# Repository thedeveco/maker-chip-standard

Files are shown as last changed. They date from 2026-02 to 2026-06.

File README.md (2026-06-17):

# MakerChip+

> [!NOTE]
> **MakerChip+** is an open hardware standard that extends the 40 mm MakerChip / MakerCoin form factor with a polarized magnetic mount, a stacked-PCB electronics tier, onboard power, and motion. A printed token can grow into a full system component while staying interoperable across creators, docks, and forks.

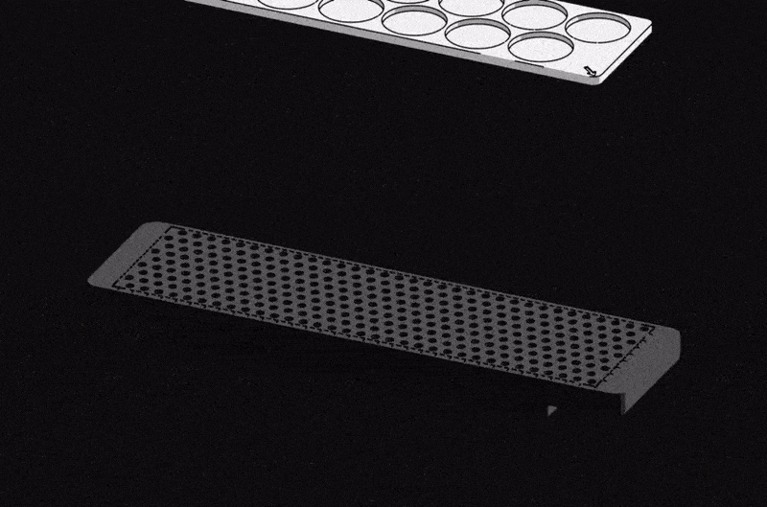
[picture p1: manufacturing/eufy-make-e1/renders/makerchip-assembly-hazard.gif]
A MakerChip+ adapter plate seating 14 chips above a 3D-printable eufyMake E1 mini bed, animated assembly loop in hazard cel-shade style


[Watch the full-quality render](https://github.com/user-attachments/assets/61c64212-e35d-4e52-ba2b-f503f769d2be) (click to play; GitHub does not autoplay video).

> [!NOTE]
> A MakerChip+ adapter plate seating 14 chips on a 3D-printable eufyMake E1 mini bed, rendered in Delta's hazard cel-shade style. The mini bed carries the same grid pattern as the ULTIM8 jig for cross-compatibility, and the adapter uses the MakerChip+ magnet pattern so every chip snaps into alignment. Both are in active development and testing. See [manufacturing/eufy-make-e1/](manufacturing/eufy-make-e1/).

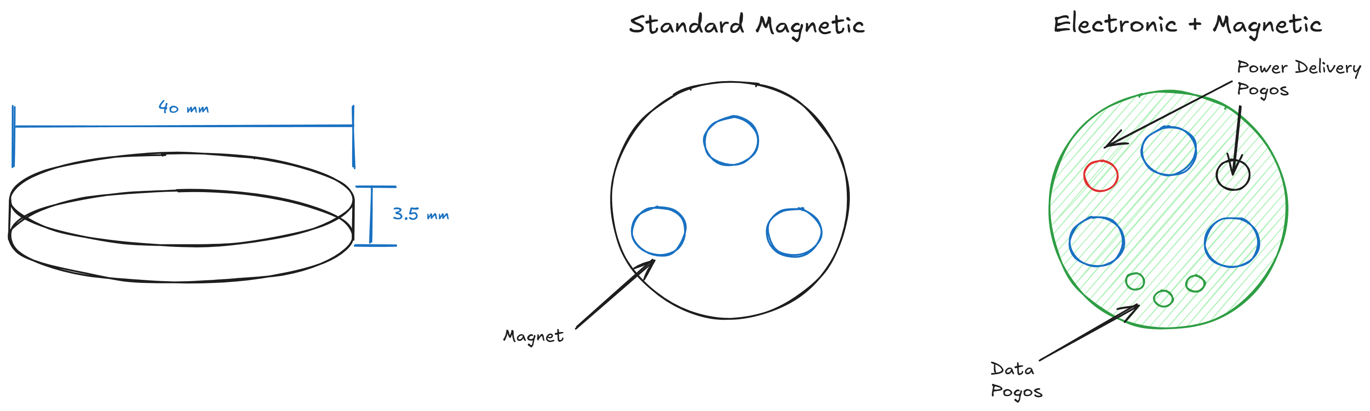
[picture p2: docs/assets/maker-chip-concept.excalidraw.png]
A small round 3D-printed chip and its layered concept diagram


## What it is

The original [MakerChip](https://makerworld.com/en/models/415825-makerchip-maker-chip-the-new-makercoin) (by [K2_Kevin](https://makerworld.com/en/@K2_Kevin), descended from the maker community's [Maker Coin](https://www.makersmuse.com/maker-s-muse-maker-coin) tradition) is a 40 mm 3D-printed token: a personalized calling card you print, trade, and collect.

MakerChip+ keeps that exact form factor and asks one question: what if the chip could do more than sit in a pocket? The standard defines the rules that let a token become magnetic, then electronic, then powered, then active, without ever breaking compatibility with the printed original or with the docks built for it.

It is a **specification**, not a single product. You build a MakerChip+ by picking a capability tier and following the spec for that tier.

## The capability tiers

| Tier | Name | What it adds |
|---|---|---|
| `1.x` | 3D Printed | The passive printed token (NFC sticker, multicolor, resin) |
| `2.x` | Magnetic Interface | Polarized magnet pair: the chip becomes mountable and orientable |
| `3.x` | PCB Stack | 3-layer PCB with the 8-pad interface, LEDs, MCU, onboard NFC |
| `4.x` | Self-Powered | Energy harvesting, battery, display, radio: no dock required |
| `5.x` | Motion | PCB coil motor, haptics, actuators: the chip moves on its own |

Higher tiers are a superset of lower ones. A `3.x` chip still mounts in a `2.x` dock; a `2.x` dock ignores the electronics it does not understand. The [compatibility rules](spec/README.md#compatibility-rules) keep the whole ecosystem interoperable.

## Quickstart (build a chip)

1. **Pick a tier** that matches what you want to ship (start at `1.x` or `2.x`).
2. **Read the spec** for that tier in [`spec/`](spec/) and preserve the [core invariants](spec/README.md#core-invariants): 40 mm diameter, 3.6 mm thickness, polarized orientation.
3. **Build it**, starting from the reference design for your tier:
   - **`1.x`** needs only a 3D printer - grab a print-ready model in [`hardware/makerchip-2.0/`](hardware/makerchip-2.0/).
   - **`2.x` magnetic** - start from the reference CAD ([`chip.step`](hardware/makerchip-2.0/chip.step), [`dock.step`](hardware/makerchip-2.0/dock.step), and `.3mf` prints), or fork the editable [public Onshape project](https://cad.onshape.com/documents/66dffec1c63767f9fad75111/w/110fc95ea174063827d47415/e/8618be80ab8abbf698550313).
   - **`3.x` PCB** - **start from the [Protoboard project](https://alpha.protoboard.xyz/board/pCOh7ogceIT44E7xwzadPOtLD8I3/_w6jix_-YGsyXYv-8ICmD)** (see the tip below). The [tscircuit source](hardware/pcb-tscircuit/) and a [KiCad scaffold](hardware/pcb-v3/) are here too.
4. **Tag your design** `MAJOR.MINOR[-variant]` (for example `MakerChip-3.1-LED-OG`) so others know what it interoperates with.

> [!TIP]
> **The fastest way to build an electronic chip is the Protoboard project.** Open the [live board](https://alpha.protoboard.xyz/board/pCOh7ogceIT44E7xwzadPOtLD8I3/_w6jix_-YGsyXYv-8ICmD) or import [`maker-chip-pcb-v4.protoboard`](docs/protoboard/maker-chip-pcb-v4.protoboard), and you get the entire system in one place: every part with its **datasheet**, a live **BOM** with vendors and cost, the **system / harness diagram**, and DRC validation. Fork it, swap a part, and everything updates with you. Details in [docs/protoboard/](docs/protoboard/).

## Documentation

| Document | Contents |
|---|---|
| [spec/README.md](spec/README.md) | Core invariants, versioning system, compatibility matrix |
| [spec/magnetic.md](spec/magnetic.md) | The polarized magnetic standard (>= 2.0) |
| [spec/tiers.md](spec/tiers.md) | Full major-version tiers (1.x - 5.x) and variants |
| [spec/interface.md](spec/interface.md) | The 8-pad standard electrical interface (>= 3.0) |
| [spec/docks.md](spec/docks.md) | Docks: the inverse mating part |
| [spec/roadmap.md](spec/roadmap.md) | Open questions and what must be locked before v2.0 freeze |
| [docs/protoboard/](docs/protoboard/) | **Protoboard project - the recommended 3.x starting point**: importable file plus BOM, datasheets, and system diagram |
| [hardware/makerchip-2.0/](hardware/makerchip-2.0/) | Chip + dock CAD (STEP) and print-ready 3MF models for the 2.x magnetic tier |
| [hardware/pcb-tscircuit/](hardware/pcb-tscircuit/) | The 3.x PCB defined as code (tscircuit source + rendered layer previews) |
| [hardware/pcb-v3/](hardware/pcb-v3/) | KiCad reference design (3.1-class) |
| [hardware/accessories/](hardware/accessories/) | Printable extras (chip roll / holder) |
| [manufacturing/eufy-make-e1/](manufacturing/eufy-make-e1/) | 3D-printable mini bed plate + 14-chip adapter for batch UV printing |

## Contributing

Fork it, pick a tier, preserve the invariants, tag your version, and open a PR if you have improved a reference design. Designs that deviate from the form factor or compatibility rules are welcome as forks or `-variant` releases, but do not promote to mainline. A full contributing guide is on the way.

## Credit and prior art

MakerChip+ is an independent standard built on the **concept and dimensions** of the original MakerChip / Maker Coin, not on anyone's model files. The original MakerChip by K2_Kevin is released under CC BY-NC-SA; this standard reuses only the interoperability idea and the 40 mm form factor (specifications are not copyrightable) and ships its own clean-room designs.

- Original MakerChip: https://makerworld.com/en/models/415825-makerchip-maker-chip-the-new-makercoin
- MakerChip community catalog: https://makerchip.app
- Maker Coin origin (Maker's Muse / Angus Deveson): https://www.makersmuse.com/maker-s-muse-maker-coin

## License

This project is licensed under **Creative Commons Attribution-ShareAlike 4.0 International (CC BY-SA 4.0)**. You may share, remix, and build commercially, provided you give attribution and license derivatives under the same terms. See [LICENSE](LICENSE) once added (license file pending in the next setup phase).

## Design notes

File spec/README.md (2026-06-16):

# MakerChip+ Standard

The reference standard for **MakerChip+**: a 40 mm x 3.6 mm poker-chip-sized open-hardware artifact. This document defines the **form-factor invariants**, the **versioning system** (major capability tiers, minor augmentations), and the **compatibility rules** that keep the ecosystem interoperable across creators, sponsors, and forks.

This directory is the standard. The repository root [README](../README.md) is the front door.

- [Magnetic standard (>= 2.0)](magnetic.md)
- [Major version tiers (1.x - 5.x) and variants](tiers.md)
- [8-pad standard interface (>= 3.0)](interface.md)
- [Docks](docks.md)
- [Roadmap and open questions](roadmap.md)

---

## 0. Origin

MakerChip+ standardizes a magnetic and electronic mounting system for the MakerChip, originally devised by [K2_Kevin](https://makerworld.com/en/models/415825-makerchip-maker-chip-the-new-makercoin), itself an evolution of the community [Maker Coin](https://www.makersmuse.com/maker-s-muse-maker-coin) created by Angus Deveson (Maker's Muse).

This standard is independent of any original model files. It reuses only the interoperability concept and the 40 mm form factor (specifications are not copyrightable) and defines its own clean-room designs and license. See the root README for full credit and prior art.

### Concept

Layered concept diagram of the chip showing bottom, middle, and top stack

### Prototype

- [Onshape CAD file](https://cad.onshape.com/documents/66dffec1c63767f9fad75111/w/110fc95ea174063827d47415/e/8618be80ab8abbf698550313)

---

## 1. Core invariants

These never change. Anything that breaks them is a **branch**, not a version.

| Property | Spec | Rationale |
| --- | --- | --- |
| Diameter | **40 mm** | Standard poker-chip footprint; tactile recognition |
| Thickness | **3.6 mm** (0.8 + 2.0 + 0.8) | Fits standard poker-chip racks/storage; allows 3-layer PCB stack |
| Stack convention | bottom / middle / top | Layered architecture even for 3D-printed chips |
| Orientation | **Polarized** (see [magnetic.md](magnetic.md)) | Forward-compatibility with all electrical/mechanical interfaces  |
| License | **CC BY-SA 4.0** | Share, remix, and sell with attribution and same-license terms |

> [!WARNING]
> **Form factor is the contract.** All major versions MUST preserve diameter, thickness, and orientation polarity. A "MakerChip+" that is 50 mm or 5 mm thick is a different product. Call those branches/variants explicitly (for example `MakerCoin`, `MakerSlab`).

---

## 2. Versioning system

### 2.1 Semantics

`MAJOR.MINOR[-VARIANT]`

- **MAJOR** - capability tier. Each tier unlocks a new class of functionality (passive form -> magnetic interface -> electronics -> power -> motion). Higher tier = strict superset of lower-tier capabilities (or compatible substitution).
- **MINOR** - additive augmentation within a tier. Does not break compat with same-major peers. Can be combined freely.
- **VARIANT** - named branch for non-conforming or experimental designs (for example `2.x-maglev`, `3.x-mini`). Variants do not promote to mainline.

### 2.2 Examples

| Version | Meaning |
|---|---|
| `1.0` | Plain 3D-printed disc |
| `1.1` | 3D print + embedded NFC sticker |
| `1.2+1.3` | 3D print + NFC + multicolor surface |
| `2.0` | Magnetic interface added |
| `3.1` | PCB stack with LEDs |
| `4.2-eink` | Self-powered chip with e-ink, branch variant |
| `5.0-experimental` | Motion-capable prototype |

### 2.3 Compatibility rules

> [!NOTE]
> **Forward/backward compat.** A chip at version `N.x` MUST physically interoperate with any accessory/dock built for version `M.x` where `M <= N`, provided the accessory only relies on capabilities present in version `M`. Higher-tier features are simply not used.

This works because:
- Form factor is identical
- Magnet positions/polarity (>= 2.0) never move
- Pad positions (>= 2.2) never move
- 8-pad signal map (>= 3.0) is fixed (see [interface.md](interface.md))

---

## 8. Compatibility matrix

| Capability | 1.x | 2.x | 3.x | 4.x | 5.x |
|---|---|---|---|---|---|
| 40mm x 3.6mm form factor | Yes | Yes | Yes | Yes | Yes |
| NFC tag (sticker or chip) | 1.1+ | Yes | 3.3+ | Yes | Yes |
| Magnet alignment | No | Yes | Yes | Yes | Yes |
| Bottom contact pads | No | 2.2+ | Yes | Yes | Yes |
| 8-pad standard signals | No | No | Yes | Yes | Yes |
| Onboard MCU | No | No | 3.2+ | Yes | Yes |
| Self-powered operation | No | No | No | Yes | Yes |
| Active motion | No | No | No | No | Yes |

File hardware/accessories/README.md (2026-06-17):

# Accessories

Printable extras for the MakerChip+ ecosystem.

| File | What it is |
|---|---|
| `maker-chip-roll.3mf` | A roll / holder for storing and carrying a stack of chips |

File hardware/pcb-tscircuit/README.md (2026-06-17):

# PCB (tscircuit source)

The MakerChip+ 3-layer PCB defined as code with [tscircuit](https://tscircuit.com). This is the editable source behind the `3.x` PCB tier - the same board that is mirrored and validated on [Protoboard](../../docs/protoboard/).

## Layers

| File | Layer |
|---|---|
| [`top.circuit.tsx`](top.circuit.tsx) | Top PCB - silkscreen art and LEDs |
| [`middle.circuit.tsx`](middle.circuit.tsx) | Middle PCB - cutouts for components and the magnet pair |
| [`bottom.circuit.tsx`](bottom.circuit.tsx) | Bottom PCB - the 8-pad pogo interface |
| [`shared.tsx`](shared.tsx) | Shared dimensions and helpers |

Rendered previews of every layer (PCB + schematic) are in [`__snapshots__/`](__snapshots__/). Branding/glyph helpers (`omega-glyph.ts`, `lucide-magnet.ts`, `oshw-logo.ts`, `branding-paths.ts`) and build/export scripts live in [`scripts/`](scripts/).

## Build

Requires [bun](https://bun.sh) and the tscircuit CLI (`tsci`).

```
bun install
tsci dev      # live preview in the browser
```

> [!NOTE]
> `node_modules/`, `dist/`, and tscircuit caches are gitignored. Third-party datasheets referenced during design (for example a micro-battery PDF) are not redistributed here.

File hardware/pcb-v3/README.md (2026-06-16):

# PCB v3 - MakerChip+ Reference Design (3.1-class)

KiCad project for the `3.x` PCB-stack tier of the [MakerChip+ standard](../../spec/README.md). This is the electronic MakerChip+: a 40 mm 3-layer PCB stack powered through the 8-pad pogo-pin interface.

> [!NOTE]
> These KiCad files are an early scaffold. The validated design currently lives as the live Protoboard project "Maker Chip PCB - V3"; see the [snapshot](../../docs/protoboard/README.md) for the parts list, BOM, and electrical specs.

## Specifications

- 40 mm diameter, 3.0 to 3.6 mm thick (0.8 + 2.0 + 0.8 mm stack)
- Powered via a base-station / dock motherboard through the [8-pad interface](../../spec/interface.md)
- `3.1`-class: 4 white LEDs for an internal glow effect, ATtiny85 MCU, two 15 x 2 mm magnets, NFC tag

## Files

| File | Purpose |
|---|---|
| `emakerchip.kicad_pro` | KiCad project |
| `emakerchip.kicad_sch` | Schematic |
| `emakerchip.kicad_pcb` | PCB layout |

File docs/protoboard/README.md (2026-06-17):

# Protoboard Project

[Protoboard](https://protoboard.xyz) is where the MakerChip+ PCB is designed and validated, and it is the **single best starting point for a `3.x` build**. Instead of chasing parts and specs across a dozen tabs, the board hands you the entire system in one place.

## Open or import it

- **Live board:** https://alpha.protoboard.xyz/board/pCOh7ogceIT44E7xwzadPOtLD8I3/_w6jix_-YGsyXYv-8ICmD
- **Importable file:** [`maker-chip-pcb-v4.protoboard`](maker-chip-pcb-v4.protoboard) - download it and open at [alpha.protoboard.xyz](https://alpha.protoboard.xyz) to load the whole project locally.

## What you get for free

- Every component with its **datasheet** attached
- A live **BOM** with vendors, pack sizes, and per-board cost
- The **system / harness diagram** - how the 8-pad interface wires to the ATtiny85 and the LEDs
- **DRC** validation and design notes

This is why we point builders at Protoboard first: fork the board, swap a part, and the BOM, datasheets, and connection checks update with you.

## V3 snapshot (2026-04-30)

The markdown below is an exported snapshot of the earlier **Maker Chip PCB - V3** board (`Qy7JVPyQZbhWuvUfJOMx8`). The live board above is the current MakerChip+ design; these files are kept as a readable, offline record.

- [board-summary.md](board-summary.md) - parts, harnesses, electrical specs, layout
- [plan.md](plan.md) - requirements, tasks, tags, open considerations
- [bom.md](bom.md) - bill of materials with vendors, pack sizes, per-board cost
- [session-log.md](session-log.md) - log of changes made via the Protoboard MCP

## Version history

Earlier Protoboard JSON exports are in [`versions/`](versions/): `v1`, `v2`, `v3`.

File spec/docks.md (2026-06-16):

# Docks

Back to [standard overview](README.md).

A **Dock** is the inverse of a chip: the interface a MakerChip+ plugs into. Docks are how chips do anything beyond sitting in a pocket. The standard defines the chip; docks are built to spec so any compliant chip can interface with any compliant dock at the same tier or below.

> [!NOTE]
> **Dock = inverse of chip.** If the chip exposes magnets at fixed polarity and pads at fixed positions, the dock provides the matching mating magnets (opposite polarity for snap-in alignment) and pogo pins (or copper pads) at the same coordinates. The polarized magnet pair guarantees the chip can only seat one way, so pads always line up correctly.

A reference `2.0` dock (the inverse of the magnetic chip) is provided as CAD in [`hardware/makerchip-2.0/dock.step`](../hardware/makerchip-2.0/dock.step).

## What docks deliver

Depending on chip tier:

- **Mechanical hold** (>= 2.0) - magnetic snap-in. The chip stays put on a hat, badge, lanyard, wall, etc.
- **Power** (>= 2.2 / >= 3.0) - VCC/GND through pads. Docks supply 5V to drive LEDs, MCUs, displays.
- **Data** (>= 3.0) - DATA/CLK/CS lines for read/write. Reprogram a chip, transfer game data, register an ID.
- **Identification** (>= 3.0 or >= 1.1) - read NFC/RFID or pad-based ID to authenticate the chip and trigger a system response (door unlock, profile load, score increment).

## Example docks

| Dock type | Description | Chip tier needed |
|---|---|---|
| **Hat clip / lanyard / pin** | Single magnet pocket; chip snaps in, no electronics | >= 2.0 |
| **Multi-slot badge** | Wearable badge with several flush cutouts; swap chips in/out for display, ID, art | >= 2.0 (display variants >= 3.x) |
| **Charging dock** | Pogo-pin base supplies 5V; LEDs/MCU on chip light up | >= 3.0 |
| **Reader / scanner** | Reads NFC tag or pad-based ID; reports to host system | >= 1.1 (NFC) or >= 3.0 (pads) |
| **Door unlock dock** | Magnetic seat + pogo pins, reads chip ID, triggers actuator/access system | >= 3.0 |
| **Game console / cartridge slot** | Pogo pins + storage protocol; chip acts as removable cartridge or save token | >= 3.5 |
| **Display kiosk** | Multi-chip array; each chip drives a tile of a larger display | >= 3.4 (RGB) |

## Why docks matter at higher tiers

Low-tier (1.x) chips work passively; a sticker is enough. Higher tiers depend on the dock to be useful. A `3.2` chip with an MCU is a paperweight without a dock supplying power. A `3.5` storage cartridge is just plastic without a system that knows how to read it.

Designing a tier without designing the matching dock is half the work. **Mainline tier specs SHOULD ship with at least one reference dock design.**

> [!NOTE]
> **VIP access dock (Fallout-style "Platinum Chip").** At an event, attendees receive a `1.1` or `3.x` Platinum Chip: a limited-run, serialized MakerChip+. To enter the VIP area, the attendee places the chip onto a wall-mounted **access dock**. The polarized magnets snap the chip into the only correct orientation, the dock reads the chip's NFC or pad-based ID, validates it against an authorized list, and unlocks the door. The same hardware pattern works for badge unlocks, hidden booths, scavenger hunts, or backstage access.

## Dock conformance

Docks SHOULD declare the **maximum tier** they support (`Dock 3.0` handles >= 3.0 chips and ignores higher-tier features on `4.x`/`5.x` chips placed in it). A `Dock 5.x` is the inverse: it must handle every tier below it gracefully.

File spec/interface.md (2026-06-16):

# The 8-Pad Standard Interface (>= 3.0)

Back to [standard overview](README.md).

> [!WARNING]
> **Still in development.** The 8-pad map below is the **current working draft** for the `3.x` electrical contract. Pad count, positions, and signal assignments may change or expand (more pads, alternate maps for specialized variants) before being frozen. Treat as provisional until marked stable in this repo.

Defined on the bottom face. 3 mm exposed copper, fixed positions.

| Pad | Signal | Notes |
|---|---|---|
| 1 | VCC (5V) | Power in |
| 2 | GND | Ground |
| 3 | DATA | MOSI / SDA / generic |
| 4 | CLK | SCK / SCL |
| 5 | CS / RST | Chip select / reset |
| 6 | MISO / GPIO | Bidir |
| 7 | GPIO / PWM | Bidir |
| 8 | ANALOG | ADC-capable |

> [!NOTE]
> **Why this map.** It covers SPI, I2C, UART (with pin reuse), and analog/PWM in 8 pads. Every common MCU footprint maps cleanly. Pads 1-2 are always power; 3-8 are programmable.

## Reference pinout (ATtiny85)

The `3.1` reference design maps the 8 pads to an ATtiny85 as follows:

| Pad | Signal | ATtiny85 Pin |
|-----|---|---|
| 1 | VCC (5V) | Pin 8 |
| 2 | GND | Pin 4 |
| 3 | DATA (MOSI/SDA)  | Pin 5 (PB0) |
| 4 | CLK (SCK/SCL) | Pin 7 (PB2) |
| 5 | CS/RST | Pin 1 (RESET) |
| 6 | MISO/GPIO | Pin 6 (PB1) |
| 7 | GPIO/PWM | Pin 3 (PB4) |
| 8 | ANALOG | Pin 2 (PB3/ADC3)|

Pad positions and the full board breakdown live in the reference snapshot: see [`docs/protoboard/bom.md`](../docs/protoboard/bom.md) and [`docs/protoboard/board-summary.md`](../docs/protoboard/board-summary.md).

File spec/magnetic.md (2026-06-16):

# The Magnetic Standard (>= 2.0)

Back to [standard overview](README.md).

The defining innovation. Two **15 x 2 mm N52 disc magnets** embedded in the middle layer at fixed positions, with **opposite polarities** facing the same direction.

> [!TIP]
> **Why polarized.** Two flipped magnets means the chip can only seat in **one rotational orientation** when placed against any mating surface with a matching magnet pattern. This eliminates the "user flips chip upside-down" failure mode for electrical pads, NFC antennas, and so on. Future tiers (PCB pads, displays, antennas) inherit this orientation lock for free.

## Magnet placement spec

*(Exact center-to-center distance, tolerance, and reference axis to be locked in the v2.0 spec - currently 16 mm CtC. Placement diagram pending; see [roadmap.md](roadmap.md).)*

The reference chip and mating dock CAD live in [`hardware/makerchip-2.0/`](../hardware/makerchip-2.0/) (`chip.step`, `dock.step`), modeled in the [public Onshape project](https://cad.onshape.com/documents/66dffec1c63767f9fad75111/w/110fc95ea174063827d47415/e/8618be80ab8abbf698550313).

## Optional shielding (2.x minor)

A thin steel shim or mu-metal layer on the **non-interface side** can null the magnetic field on that face, useful when the back of the chip is meant to sit against a credit card, hard drive, or another magnet-sensitive surface.

## MagLev variant (`2.x-maglev`)

A floating-magnet implementation using a commercial maglev base plus an embedded ferromagnetic disc. This is a branch variant; it does not deprecate the `2.x` mainline. See the [Hackaday MagLev tag](https://hackaday.com/tag/maglev/) for prior art.

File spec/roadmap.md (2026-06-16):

# Roadmap and Open Questions

Back to [standard overview](README.md).

> [!IMPORTANT]
> **Things to lock down before the v2.0 freeze:**
> - [ ] Exact magnet center-to-center distance + tolerance (currently 16 mm CtC, plus/minus ?)
> - [ ] Magnet orientation reference axis (which way is "+X"? silkscreen marker?)
> - [ ] Pad positions for the 2.2 passive-pad variant: same map as 3.0 8-pad, or a simpler 2-pad?
> - [ ] **8-pad map freeze** (currently in development, may expand)
> - [ ] Reference dock design(s) per tier, bundled with the mainline tier spec
> - [ ] Conformance test / certification process, or is this purely honor-system?
> - [ ] NFC antenna footprint reservation in the 3.0 PCB stack (so 3.0 -> 3.3 does not require a board redesign)
> - [ ] Magnet placement diagram image (see [magnetic.md](magnetic.md))

## Resolved

- **License decision** - settled on CC BY-SA 4.0. See the root [README](../README.md#license). LICENSE file to be added in the repo setup phase.

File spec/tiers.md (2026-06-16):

# Major Version Tiers and Variants

Back to [standard overview](README.md).

## 4. Major version tiers

### `1.x` - 3D Printed (passive form)

The entry tier. Anyone with a 3D printer can produce a compliant chip.

| Minor | Augmentation | Notes |
|---|---|---|
| 1.0 | Plain mono filament print | Baseline; no inserts |
| 1.1 | Pause-print **NFC tag insert** | NTAG213/215 sticker dropped mid-print. See [Bambu NFC tag](https://us.store.bambulab.com/products/nfc-tag-with-adhesive?skr=yes&id=42872074240136&modelId=415825) |
| 1.2 | Multicolor / AMS print | Logos, identity art baked in |
| 1.3 | Laser-etched or engraved surface | Post-process detail |
| 1.4 | Multi-material (TPU rim, etc.) | Grip, durability |
| 1.5 | Resin / SLA finish | High-detail collectible runs |

> [!NOTE]
> **Reference build.** A `1.1+1.2` chip = multicolor 3D-printed disc with a hidden NFC tag. Looks like swag, scans like a key.

### `2.x` - Magnetic Interface

Adds the polarized magnet pair. **First tier where the chip becomes a system component**, not just a token. Full spec in [magnetic.md](magnetic.md).

| Minor | Augmentation |
|---|---|
| 2.0 | Dual 15 x 2 mm magnets, opposite polarity (mainline spec) |
| 2.1 | + Steel shim shielding (one-sided field) |
| 2.2 | + Bottom-side **passive contact pads** (no electronics, just brass/copper inserts for snap-in chargers, ID readers, etc.) |

> [!NOTE]
> **Why 2.x is a tier and not a 1.x minor.** Adding magnets fundamentally changes what the chip *is*. It becomes mountable, orientable, and modular. Every higher tier inherits this.

> [!NOTE]
> **Reference CAD.** The `2.0` chip and its mating dock are in [`hardware/makerchip-2.0/`](../hardware/makerchip-2.0/).

### `3.x` - PCB Stack (electronics, externally powered)

Three-layer PCB sandwich. The middle layer has cutouts for components and magnets. The bottom layer exposes the **8-pad standard interface** (see [interface.md](interface.md)) for power and data via pogo-pin docks. The top layer is the canvas (silkscreen, art, surface-mount LEDs).

| Minor | Augmentation |
|---|---|
| 3.0 | Bare 3-layer PCB stack with 8-pad interface |
| 3.1 | + Indicator LEDs (current `Maker Chip PCB - V3` reference design) |
| 3.2 | + MCU (ATtiny85 or equivalent) |
| 3.3 | + **On-PCB NFC antenna** + tag IC (NT3H2111, ST25DV): replaces sticker, MCU can read/write |
| 3.4 | + Addressable RGB LEDs (WS2812 / SK6812) |
| 3.5 | + Onboard storage / data-cartridge variant ("DOOM-on-a-chip" use case) |

> [!NOTE]
> **Reference design.** The current open-source PCB lives in this repo as a `3.1`-class design. See [`hardware/pcb-v3/`](../hardware/pcb-v3/) for the KiCad project and [`docs/protoboard/`](../docs/protoboard/) for a snapshot of the live Protoboard project.

**Prior art / references:**
- [Hackster: Light-up poker chip](https://www.hackster.io/AlexWulff/light-up-poker-chip-7fa67f) - LED chip ref (3.1)
- [Reddit: PCB poker set](https://www.reddit.com/r/electronics/comments/opowu0/pcb_poker_set/) - full set fabrication
- [PokerChipForum: RFID table experiment](https://www.pokerchipforum.com/threads/experimenting-with-a-diy-rfid-table-and-broadcast-overlay.88715/post-2141059) - application
- [Reddit: NFC antenna design advice](https://www.reddit.com/r/PrintedCircuitBoard/comments/1f5q0j3/need_advice_on_nfc_antenna_design_and_component/) - 3.3 antenna sizing
- [GitHub: PCB Business Card](https://github.com/Raziz1/PCB_Business_Card) - antenna trace example
- [Instructables: PCB Business Card with NFC](https://www.instructables.com/PCB-Business-Card-With-NFC-Make-Yours-With-NFC-QR-/) - build guide
- [PCBSync: NFC antenna PCB](https://pcbsync.com/nfc-antenna-pcb/) - antenna design reference

### `4.x` - Self-Powered

Onboard energy. The chip stops needing a dock to do anything.

| Minor | Augmentation |
|---|---|
| 4.0 | Wireless power harvesting (Qi pad, NFC field, RF) |
| 4.1 | + Internal battery (LiPo / LiSOCl2 coin) |
| 4.2 | + Power-management IC + deep-sleep modes |
| 4.3 | + E-ink / Memory LCD display |
| 4.4 | + Always-on indicator (low-current LED) |
| 4.5 | + BLE / sub-GHz radio (full wireless duplex) |

**References:**
- [Instructables: Wireless energy transmission via PCB](https://www.instructables.com/Wireless-Energy-Transmission-System-Only-Using-PCB/)
- [ABLIC wireless power ICs](https://www.ablic.com/en/semicon/products/rtc/wireless-power-ic/intro/)
- [MDPI: Electronics 13(2), 426](https://www.mdpi.com/2079-9292/13/2/426) - academic ref
- [Analog Devices AN-138FC](https://www.analog.com/en/resources/app-notes/an-138fc.html)
- [TI E2E: wireless power transfer](https://e2e.ti.com/support/power-management-group/power-management/f/power-management-forum/380718/wireless-power-transfer)

### `5.x` - Motion

Active mechanical capability. The chip moves, vibrates, or actuates something on its own.

| Minor | Augmentation |
|---|---|
| 5.0 | PCB coil motor (planar / axial-flux) |
| 5.1 | Haptic / vibration motor (LRA or coin) |
| 5.2 | Microactuator / piezo |
| 5.3 | Combined motion + display + power (full active chip) |

**References:**
- [Hackaday: PCB motor tag](https://hackaday.com/tag/pcb-motor/)
- [PCBWay: PCB motor design guidelines](https://www.pcbway.com/blog/Engineering_Technical/PCB_Motor_Design_Guidelines.html)

---

## 5. Branches and variants

Use a `-suffix` instead of bumping major when the design **deviates from the form factor or compat rules** but is still MakerChip+-adjacent.

| Variant | Description |
|---|---|
| `2.x-maglev` | Floating-magnet implementation using a commercial maglev base |
| `3.x-mini` | Reduced-diameter PCB chip (for example 25 mm): non-conforming, explicit |
| `3.x-thick` | >3.6 mm stack for high-component-count PCB |
| `*-collectible` | Limited-run sponsor/creator edition (for example a Fallout collab) |
| `*-cartridge` | Non-standard pad map for a proprietary dock (for example a game system) |

> [!WARNING]
> **Variants do not promote.** A variant never becomes the next mainline major. If a deviation proves valuable enough to absorb, mainline gets the upgrade with a new major number, NOT by adopting the variant's suffix.

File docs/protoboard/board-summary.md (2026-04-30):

# Maker Chip PCB - V3 — Board Summary

- **Board ID:** `Qy7JVPyQZbhWuvUfJOMx8`
- **URL:** https://alpha.protoboard.xyz/board/pCOh7ogceIT44E7xwzadPOtLD8I3/Qy7JVPyQZbhWuvUfJOMx8
- **Parts:** 20 (17 functional + 2 magnets + 1 NFC tag, 14 unique templates)
- **Harnesses:** 20
- **DRC:** PASS

## Description

A poker-chip-sized PCB device with 3 stacked layers (2× 0.8 mm + 1× 2 mm middle). Features 4 white LEDs for internal glow effect, powered via pogo-pin interface. Middle layer contains 15 mm magnets and component cutouts.

## Stack Structure

- **Top PCB (0.8 mm):** Silkscreen design on top, LEDs/resistors on bottom
- **Middle PCB (2 mm):** Cutouts for LEDs, resistors, ATtiny85, and magnets; two 15×2 mm magnets with opposite polarities
- **Bottom PCB (0.8 mm):** 8× 3 mm copper pads for pogo pins on bottom; traces and optional components on top

## 8-Pad Standard Interface

| Pad | Signal | ATtiny85 Pin |
|-----|---|---|
| 1 | VCC (5V) | Pin 8 |
| 2 | GND | Pin 4 |
| 3 | DATA (MOSI/SDA)  | Pin 5 (PB0) |
| 4 | CLK (SCK/SCL) | Pin 7 (PB2) |
| 5 | CS/RST | Pin 1 (RESET) |
| 6 | MISO/GPIO | Pin 6 (PB1) |
| 7 | GPIO/PWM | Pin 3 (PB4) |
| 8 | ANALOG | Pin 2 (PB3/ADC3)|

## Electrical

- Supply: 5 V DC via pogo pins
- LEDs: 4× white in parallel, each with 120 Ω series resistor
- Total LED current: ~60 mA (4 × 15 mA)
- ATtiny85 drives PWM pulse effects on PB4

## Parts (with positions)

| Name | Template ID | Position (x, y) |
|---|---|---|
| White LED 1 | basic-mpjDjlaA2KYMB05qyPX1R | (-40, 640) |
| White LED 2 | basic-mpjDjlaA2KYMB05qyPX1R | (210, 640) |
| White LED 3 | basic-mpjDjlaA2KYMB05qyPX1R | (680, 620) |
| White LED 4 | basic-mpjDjlaA2KYMB05qyPX1R | (930, 620) |
| 120Ω Resistor 1 | basic-fFVpV0slY_0ycHSXpgPcp | (-40, 840) |
| 120Ω Resistor 2 | basic-fFVpV0slY_0ycHSXpgPcp | (210, 840) |
| 120Ω Resistor 3 | basic-fFVpV0slY_0ycHSXpgPcp | (680, 820) |
| 120Ω Resistor 4 | basic-fFVpV0slY_0ycHSXpgPcp | (930, 820) |
| Pad 1 - VCC (5V) | basic-NLkZFikHo6YDudwjzZbog | (400, 0) |
| Pad 2 - GND | basic-848t6FXjZg-gFcYJHxtV4 | (400, 1060) |
| Pad 3 - DATA | basic-VYPSKHr3RS2GLnCUEqvgd | (-40, 60) |
| Pad 4 - CLK | basic-IFiLhx3i8ZHFZPVNEg8n0 | (-40, 210) |
| Pad 5 - CS/RST | basic-rVRacUFPbQDq3LhNcpwAH | (-40, 360) |
| Pad 6 - MISO/GPIO | basic-_xR1FA-npyLAzmcU1FuL4 | (820, 60) |
| Pad 7 - GPIO/PWM | basic-uaMJdW7PbbgWcAmpVx_dB | (820, 220) |
| Pad 8 - ANALOG | basic-bNdPFE75fJqbc11ZdhxV5 | (820, 380) |
| ATtiny85 MCU | basic-1AGk7mINFuKOXGWMz54X8 | (400, 300) |
| Magnet 1 (N-up, 15×2 mm) | basic-YyWx7p_6bcMBmPNF_7r77 | (1180, 300) |
| Magnet 2 (S-up, 15×2 mm) | basic-YyWx7p_6bcMBmPNF_7r77 (2nd inst.) | (1180, 500) |
| NFC Tag (NTAG215, 25×25 mm) | basic-Rlhr-s9wEdMSbvUFO1J4g | (1180, 700) |

## Topology

- ATtiny85 (center) connects to all 8 pads + 4 LED chains
- Each LED → 120 Ω resistor → GND pad
- VCC pad → ATtiny85
- 20 harnesses total, all DRC-clean

## Layout Notes (info-level)

6 suboptimal handle orientations (cosmetic only, no DRC errors):
- R1, R3, R4 handles face bottom but neighbor is to side
- GND pad handle faces top but neighbor (R3) is right
- ATtiny85 ↔ White LED 1 handle pair faces wrong direction

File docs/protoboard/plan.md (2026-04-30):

# Maker Chip PCB - V3 — Plan

**Status as of 2026-04-30:** 8/8 requirements validated.

## Requirements

| # | Status | Content |
|---|---|---|
| 1 | validated  | Supply 5V DC power through pogo pin interface to illuminate 4 white LEDs |
| 2 | validated  | Each LED must have a current-limiting resistor to prevent burnout |
| 3 | validated  | LEDs must fit within cutouts in middle PCB layer (0603 package: 1.6×0.8×0.55 mm) |
| 4 | validated  | Total PCB stack thickness: 3.6 mm (0.8 + 2.0 + 0.8 mm) |
| 5 | validated  | Bottom surface must be flat with only exposed copper pads for pogo pins |
| 6 | validated  | Top surface must be flat for silkscreen design application |
| 7 | validated  | 8-Pad Standard Interface: VCC, GND, DATA, CLK, CS/RST, MISO/GPIO, GPIO/PWM, ANALOG — all 3 mm exposed copper pads |
| 8 | validated  | ATtiny85 MCU connected to pads 3–8 for ISP programming and LED pulse control |

## Tasks

### Done
- Finalize LED and resistor component selection from LCSC (NCD0603W3, RC0603FR-07120RL)
- Design LED circuit schematic (4 parallel LED strings, each with series resistor)
- Define pogo pin pad layout on bottom PCB

### To Do
- Create middle layer cutout pattern (4 LEDs, 4 resistors, 2 magnets — verify fit)
- Route traces on bottom PCB (pogo pads → component positions via vias to top PCB)
- Design top PCB silkscreen artwork (logo + LED glow cutout)
- Generate Gerber files for fabrication (all 3 PCB layers)
- Order components from LCSC (4+ LEDs, 4+ resistors)

## Tags

LED, PCB, pogo-pin, wearable

## Open Considerations

- NFC (NTAG215 sticker) added but not yet captured in requirements/cutouts. Decide whether NFC tag mounts on top, embeds in middle, or is post-assembly applied.
- Magnet placement requirement currently mentions "two 15×2 mm magnets with opposite polarities" — confirm orientation in middle layer cutouts.

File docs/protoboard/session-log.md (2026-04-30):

# Protoboard Session Log — 2026-04-30

Maker Chip PCB - V3 (`Qy7JVPyQZbhWuvUfJOMx8`) on https://alpha.protoboard.xyz

## Audit (initial state)

- 17 parts, 20 harnesses
- DRC: PASS
- 6 info-level layout warnings (suboptimal handle directions; cosmetic)
- 8 requirements, 6 validated / 2 pending
- BOM: $0.00 — no supplier prices set

## Actions Taken

### Plan: closed pending requirements

Marked validated based on board state already satisfying both:

1. **8-Pad Standard Interface** (`f6f0c128-…`) — all 8 pads present and named correctly.
2. **ATtiny85 MCU connected to pads 3–8** (`a3b752f8-…`) — 11 harnesses confirm full pad-to-MCU coverage.

### BOM: added LCSC supplier records

| Template ID | Vendor | LCSC PN | Unit USD |
|---|---|---|---|
| basic-mpjDjlaA2KYMB05qyPX1R (LED) | LCSC | C158100 | $0.012 |
| basic-fFVpV0slY_0ycHSXpgPcp (120Ω R) | LCSC | C114640 | $0.005 |
| basic-1AGk7mINFuKOXGWMz54X8 (ATtiny85) | LCSC | C89852  | $1.20 |

### Added new parts

- **Magnet (15×2 mm N52)** — single template `basic-YyWx7p_6bcMBmPNF_7r77` placed twice (Magnet 1 N-up at 1180,300; Magnet 2 S-up at 1180,500). Sourced from AplysiaTech 40-pack on Amazon (B0FNX1XP21, $25.99/pack → $0.65 ea).
- **NFC Tag (NTAG215, 25×25 mm)** — template `basic-Rlhr-s9wEdMSbvUFO1J4g` at (1180, 700). InnoHHustle 50-pack on Amazon (B0F24L4GDM, $8.99/pack → $0.18 ea).

### Final cost estimate

- Project total: **$36.26** (one pack each)
- Per-board real consumption: **~$2.78**

## Tool Errors Encountered

- `upsert_bom_supplier_record` rejected initial `{name, partNumber, priceUSD, ...}` field shape. Correct schema uses `supplierVendorName`, `supplierPartNumber`, `supplierManufacturerPartNumber`, `supplierCurrentPriceUSD`, `supplierPackQuantity`, `supplierPurchaseUrl`.
- First Amazon RFID URL returned generic homepage via `summary` mode. `text` mode on the resolved Amazon `dp` URL succeeded and returned full product specs.

## Open Items / Suggestions

- Rotate handles on R1, R3, R4, ATtiny85, LED 1, GND pad to fix the 6 info warnings (cosmetic).
- Add NFC tag to requirements (currently absent from spec) and decide its layer placement.
- Magnet/NFC parts are blank placeholders with no interfaces — consider adding interface definitions if future DRC checks should validate placement.

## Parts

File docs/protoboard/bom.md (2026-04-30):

# Maker Chip PCB - V3 — Bill of Materials

**Project total (one of each pack):** $36.26 USD
**Per-board component cost (real consumption):** ~$2.78 USD
**Pack overage:** 1 magnet pack (40) + 1 NFC pack (50) cover ~20+ boards.

## Components

| Component | Vendor | Part Number | Pack Qty | Pack Price | Unit Price | Qty/Board | Per-Board Cost |
|---|---|---|---|---|---|---|---|
| White LED (NCD0603W3) | LCSC | C158100 | 1 | $0.012 | $0.012 | 4 | $0.048 |
| 120 Ω Chip Resistor 0603 | LCSC | C114640 (RC0603FR-07120RL) | 1 | $0.005 | $0.005 | 4 | $0.020 |
| ATtiny85-20SU MCU | LCSC | C89852 | 1 | $1.20 | $1.20 | 1 | $1.20 |
| N52 Disc Magnet 15×2 mm | Amazon | B0FNX1XP21 (AplysiaTech) | 40 | $25.99 | $0.65 | 2 | $1.30 |
| NFC Sticker NTAG215 25×25 mm | Amazon | B0F24L4GDM (InnoHHustle) | 50 | $8.99 | $0.18 | 1 | $0.18 |

## Pad Components (PCB Features, No Supplier)

These are exposed copper pads on the bottom PCB — fabricated as part of the board, not purchased separately:

- Pad 1 — VCC (5 V), 3 mm
- Pad 2 — GND, 3 mm
- Pad 3 — DATA, 3 mm
- Pad 4 — CLK, 3 mm
- Pad 5 — CS/RST, 3 mm
- Pad 6 — MISO/GPIO, 3 mm
- Pad 7 — GPIO/PWM, 3 mm
- Pad 8 — ANALOG, 3 mm

## Purchase Links

- LEDs: https://www.lcsc.com/product-detail/C158100.html
- Resistors: https://www.lcsc.com/product-detail/C114640.html
- ATtiny85: https://www.lcsc.com/product-detail/C89852.html
- Magnets: https://amzn.to/4tD4pup
- NFC Tags: https://amzn.to/4n0ZIbn

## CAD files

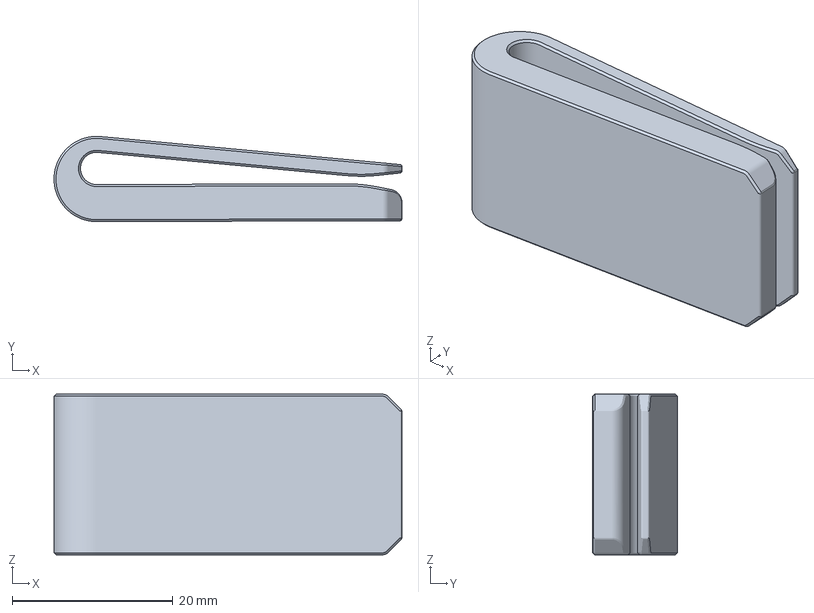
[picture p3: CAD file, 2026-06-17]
hardware/makerchip-2.0/hat-clip-dock.3mf
43.3 x 10.6 x 20.0 mm

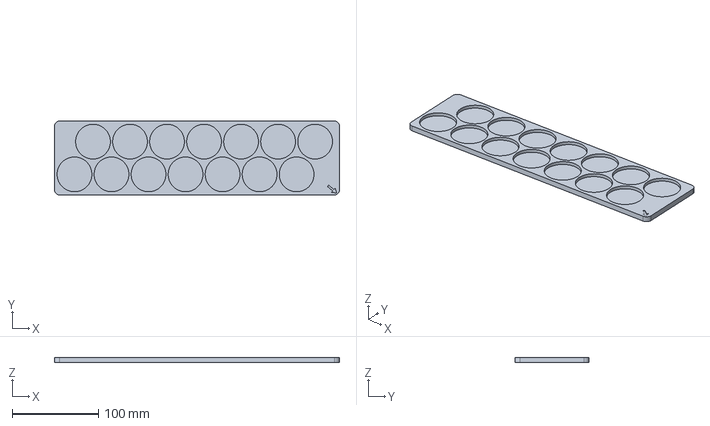
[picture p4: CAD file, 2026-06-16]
manufacturing/eufy-make-e1/adapter-plate.step
331.0 x 86.0 x 6.10 mm

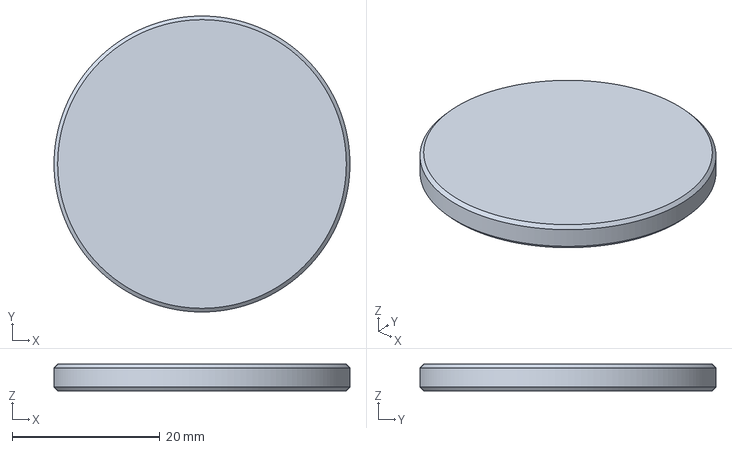
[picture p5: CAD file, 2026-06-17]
hardware/makerchip-2.0/chip-clear.3mf
40.0 x 40.0 x 3.60 mm

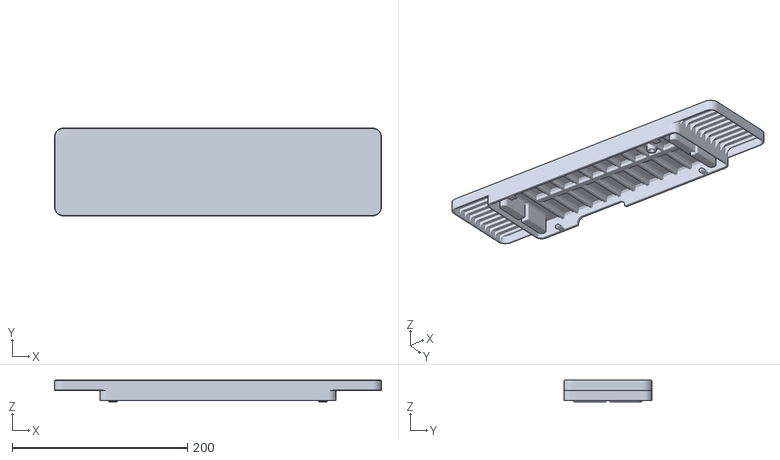
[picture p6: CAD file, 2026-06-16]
manufacturing/eufy-make-e1/og-eufy-mini-bed-low-profile-reinforced.stl
373.5 x 100.3 x 24.8

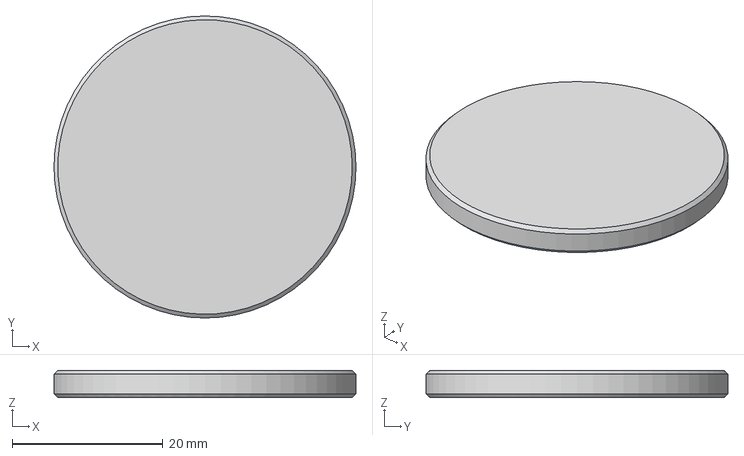
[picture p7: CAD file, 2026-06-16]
hardware/makerchip-2.0/chip.step
40.0 x 40.0 x 3.60 mm

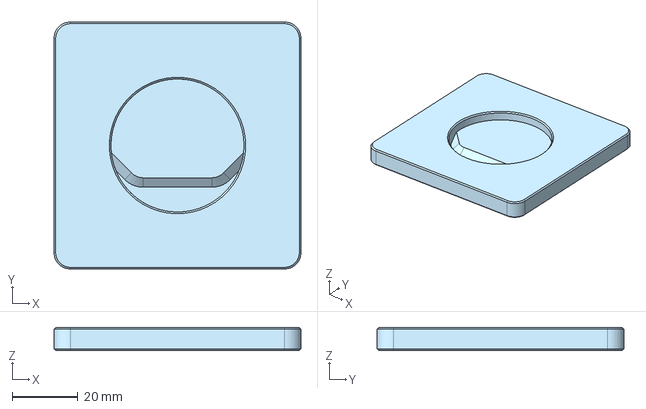
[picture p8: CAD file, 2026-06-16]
hardware/makerchip-2.0/dock.step
75.0 x 75.0 x 7.00 mm

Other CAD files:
hardware/makerchip-2.0/chip.3mf
manufacturing/eufy-make-e1/mini-bed-plate.blend

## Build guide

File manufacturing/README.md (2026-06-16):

# Manufacturing

Production tooling, jigs, and fixtures for making MakerChip+ chips at small scale.

These are not part of the standard itself; they are the practical aids that make a batch of chips repeatable to produce, decorate, and assemble.

| Platform | Contents |
|---|---|
| [eufy-make-e1/](eufy-make-e1/) | A 3D-printable mini bed plate and a 14-chip adapter for the eufyMake E1 UV printer |

> [!WARNING]
> Everything here is in active development and testing. Dimensions, magnet positions, and grid alignment are not yet frozen.

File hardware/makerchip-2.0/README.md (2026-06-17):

# MakerChip+ 2.0 - Chip and Dock CAD

Mechanical CAD for the `2.x` magnetic tier of the [MakerChip+ standard](../../spec/README.md): the chip and its mating dock.

This is the [magnetic standard](../../spec/magnetic.md) realized as solid geometry. The polarized magnet pair lets the chip seat in exactly one orientation against the dock.

## Files

| File | What it is |
|---|---|
| `chip.step` | The MakerChip+ 2.0 chip (40 mm, dual 15 x 2 mm magnet pockets) |
| `dock.step` | The mating dock (inverse magnet pattern for snap-in alignment) |
| `chip.3mf` | Print-ready MakerChip+ 2.0 chip |
| `chip-clear.3mf` | Print-ready chip, clear-window variant |
| `hat-clip-dock.3mf` | Print-ready hat-clip dock (>= 2.0) |

## Source

Both parts are modeled in the public live Onshape project:
https://cad.onshape.com/documents/66dffec1c63767f9fad75111/w/110fc95ea174063827d47415/e/8618be80ab8abbf698550313

STEP files are exported snapshots; the Onshape document is the editable source of truth.

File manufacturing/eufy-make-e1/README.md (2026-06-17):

# eufyMake E1 - Mini Bed Plate and MakerChip+ Adapter

Tooling to UV-print and decorate MakerChip+ chips in batches on the [eufyMake E1](https://www.eufymake.com/) UV printer.

> [!WARNING]
> In active development and testing. The bed plate, adapter, magnet positions, and grid alignment are not yet frozen.

## What this is

A MakerChip+ adapter plate seating 14 chips above the mini bed, animated assembly loop in hazard cel-shade style

A MakerChip+ adapter plate seating 14 chips on the mini bed, rendered in Delta's hazard cel-shade style. The looping GIF above autoplays; the [full-quality mp4](renders/makerchip-assembly-hazard.mp4) is click-to-play (GitHub does not autoplay video).

### Mini bed plate (`mini-bed-plate.blend`)

A brand-new, **3D-printable** mini bed plate for the eufyMake E1. Print it yourself, then mount custom adapters (like the chip adapter below) on top to hold whatever you want to print on.

It is based on the open-source [eufyMake E1 low-profile reinforced mini bed](https://www.printables.com/model/1395018-eufymake-e1-uv-printer-low-profile-mini-bed) by the original author (the reference STL is included as [`og-eufy-mini-bed-low-profile-reinforced.stl`](og-eufy-mini-bed-low-profile-reinforced.stl)).

The plate carries the **same grid pattern as the Wham Bam ULTIM8 jig** so adapters and fixtures are cross-compatible across both systems. For full-plate alignment, eufyMake Studio's **Calibration > Zero Point Calibration** lets you input an offset instead of visually aligning to a snapshot; see the third-party reference in [`refs/`](refs/ultim8-jig-zero-point-calibration.pdf).

### Adapter plate (`adapter-plate.step`)

A drop-on adapter that holds **14 MakerChips** in a fixed array for batch UV printing. It carries the **same magnet pattern as the MakerChip+** itself, so each chip snaps into the only correct orientation for fast, repeatable alignment and placement (the same polarized-magnet trick the [magnetic standard](../../spec/magnetic.md) uses).

## Files

| File | What it is |
|---|---|
| `mini-bed-plate.blend` | The printable mini bed plate (Blender source, ULTIM8 grid) |
| `adapter-plate.step` | 14-chip adapter with the MakerChip+ magnet pattern |
| `og-eufy-mini-bed-low-profile-reinforced.stl` | Upstream reference bed this plate is based on |
| `renders/makerchip-assembly-hazard.gif` | Looping assembly render; embedded in the READMEs (autoplays and loops) |
| `renders/makerchip-assembly-hazard.mp4` | Full-quality assembly render (hazard cel-shade style); click-to-play |
| `refs/ultim8-jig-zero-point-calibration.pdf` | Wham Bam ULTIM8 jig zero-point calibration reference (third-party) |

> [!NOTE]
> `refs/ultim8-jig-zero-point-calibration.pdf` is third-party reference material included for convenience and is **not** covered by this project's license.

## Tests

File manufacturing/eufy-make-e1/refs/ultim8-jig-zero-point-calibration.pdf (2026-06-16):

## ULTIM8 JIG ZERO POINT CALIBRATION

If you are using SnapShot to layout your graphics this is not relevant.
Zero Point Calibration is used when you are placing a full build plate or image aligned to the lower right portion of the ULTIM8 JIG MAT. You would use this to input an offset in place of visually aligning a graphic to the snapshot.

This would bypass snapshot alignment. (For Camera calibration you would use our Calibration Sheets to do a different routine.)

1. First run a calibration routine on the Eufy Bed and Mat (without ULTIM8 JIG).
In bottom right of eufyMake Studio select Calibration > Zero Point Calibration

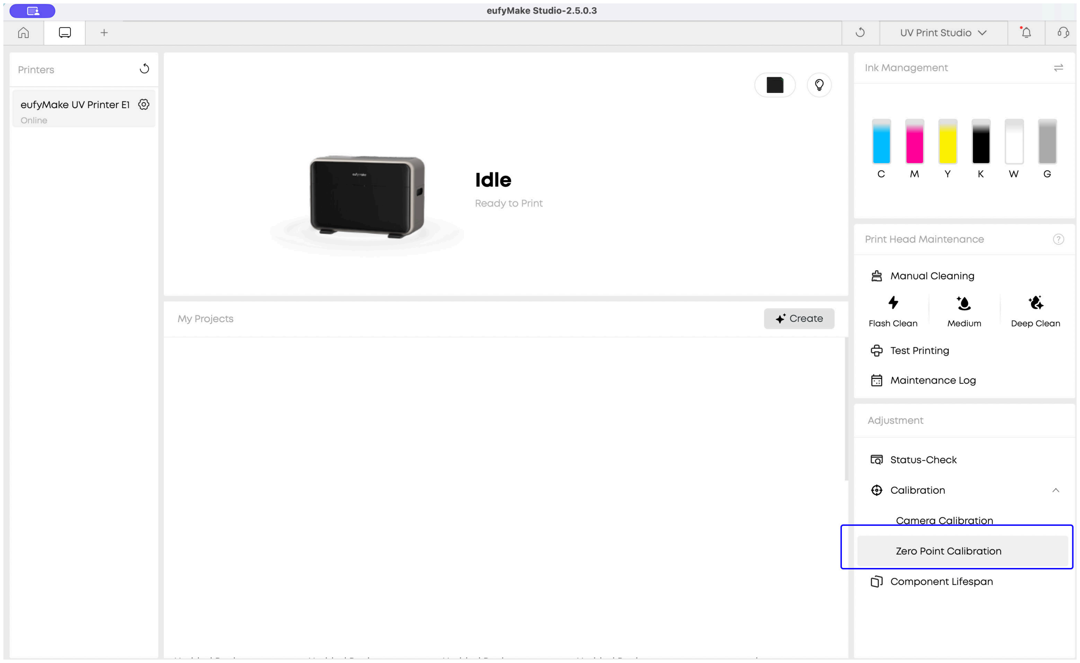
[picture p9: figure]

Run calibration routine and when finished successfully move to the next step.

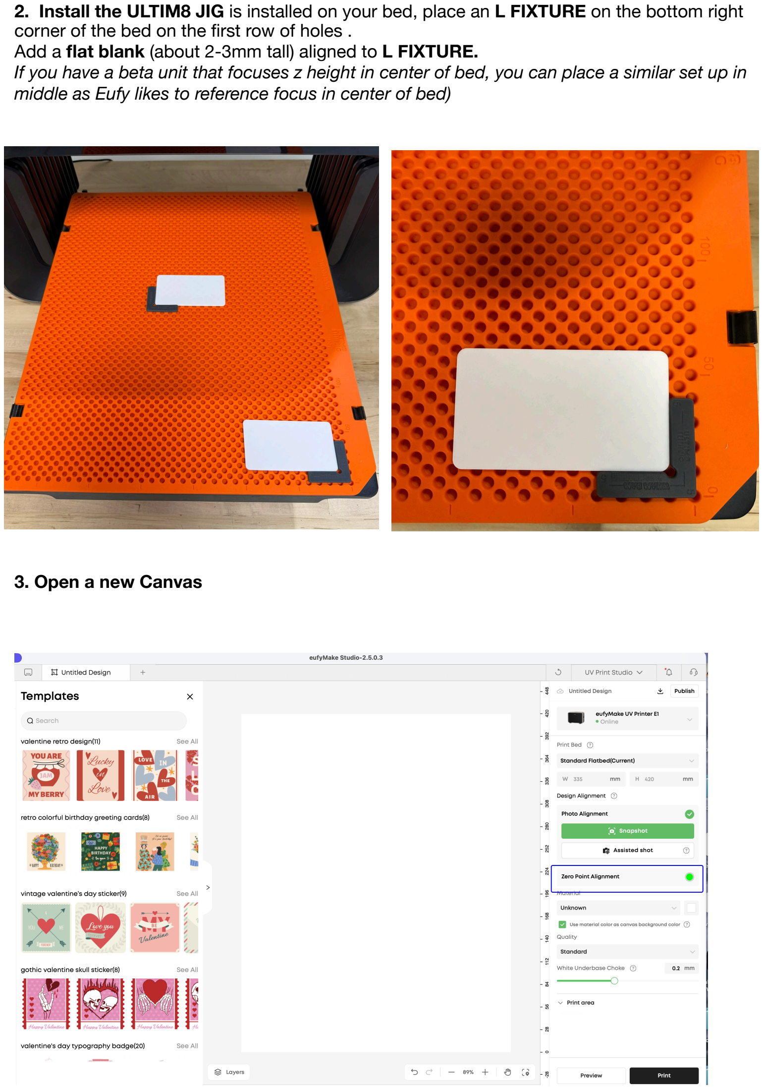
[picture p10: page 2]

2. Install the ULTIM8 JIG is installed on your bed, place an L FIXTURE on the bottom right corner of the bed on the first row of holes .
Add a flat blank (about 2-3mm tall) aligned to L FIXTURE.
If you have a beta unit that focuses z height in center of bed, you can place a similar set up in middle as Eufy likes to reference focus in center of bed)

### 3. Open a new Canvas

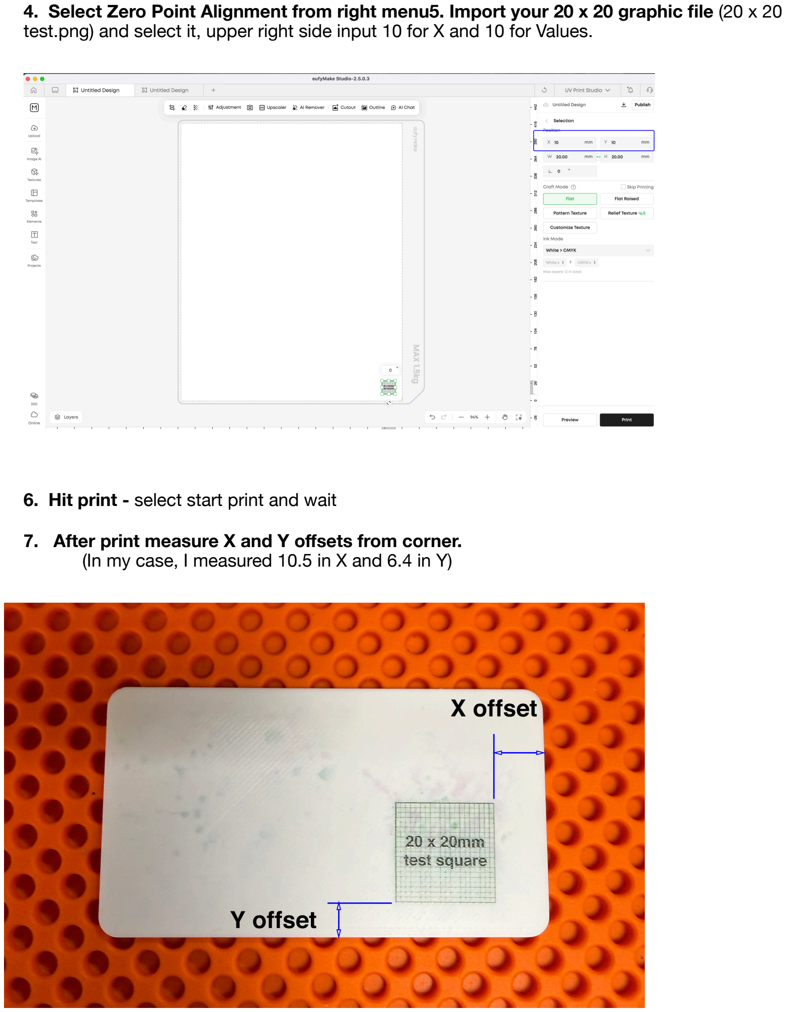
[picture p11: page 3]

4. Select Zero Point Alignment from right menu5. Import your 20 x 20 graphic file (20 x 20 test.png) and select it, upper right side input 10 for X and 10 for Values.

### 6. Hit print - select start print and wait

7. After print measure X and Y offsets from corner. (In my case, I measured 10.5 in X and 6.4 in Y)

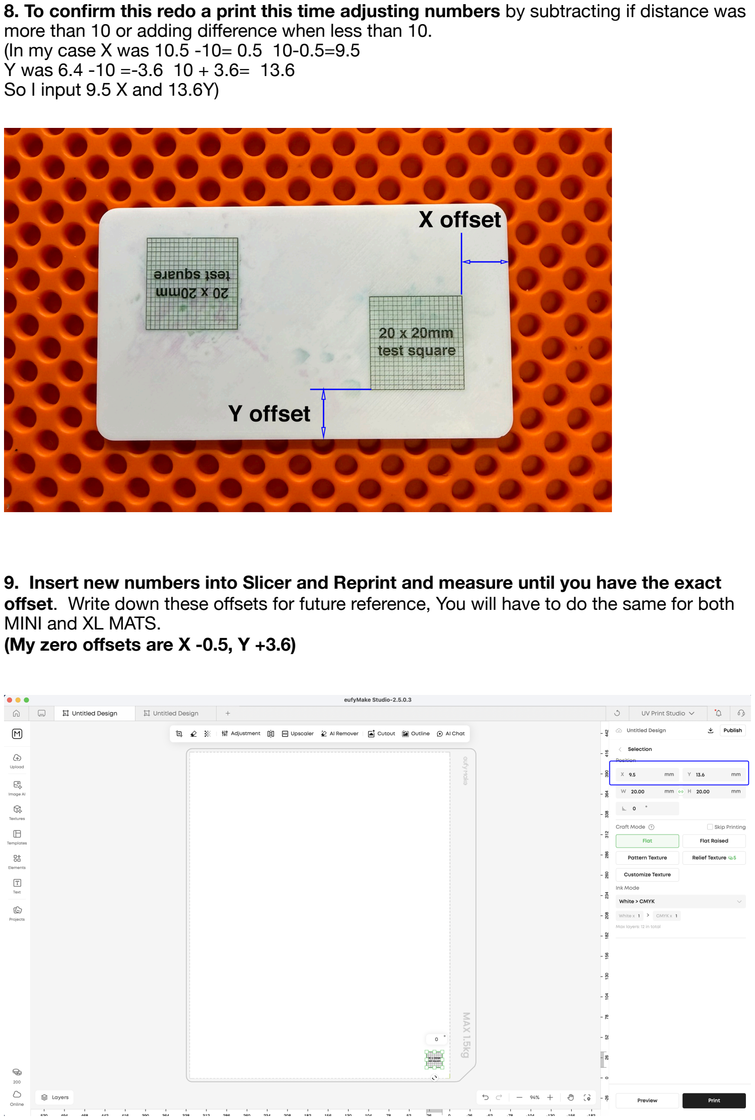
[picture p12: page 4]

8. To confirm this redo a print this time adjusting numbers by subtracting if distance was more than 10 or adding difference when less than 10.
(In my case X was 10.5 -10= 0.5 10-0.5=9.5
Y was 6.4 -10 =-3.6 10 + 3.6= 13.6
So I input 9.5 X and 13.6Y)

### 9. Insert new numbers into Slicer and Reprint and measure until you have the exact

offset. Write down these offsets for future reference, You will have to do the same for both MINI and XL MATS.
(My zero offsets are X -0.5, Y +3.6)

### 10. Once you have confirmed the exact offset, you now know the X and Y offset when

placing parts on the ULTIM8 JIG MAT.

You would use these to input offsets in graphic files that are referencing bottom right corner or Zero point.

If using Snapshot to register designs this is insignificant.

If you are using our FIXTURES be aware that the Farthest Right side of holes using a 5/5 FIXTURE is exactly at Zero and the offset should added or subtracted from Zero if using there.

The bottom set of holes using a 5/5 FIXTURE is exactly 5mm inset from the bottom edge.

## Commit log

2026-02-26 Add empty kicad design
    [emakerchip.kicad_pcb, emakerchip.kicad_sch]
2026-03-25 Add 3D print link and image to README
    Added a link to the working 3D print Onshape file and an image.
2026-04-30 Add Protoboard snapshot for Maker Chip PCB - V3
    Mirror of board state as of 2026-04-30: parts, plan, BOM, and session log
    captured via Protoboard MCP. Includes magnets and NFC tag additions plus
    LCSC/Amazon supplier records.
2026-04-30 Replace README with full MakerChip Standard
    Document defines form factor invariants (40mm × 3.6mm, polarized magnets),
    versioning system (major capability tiers, minor augmentations, variants),
    8-pad interface draft, dock concept and examples, compatibility matrix,
    and contributor guidelines. License remains pending.
2026-06-16 Reorganize as MakerChip+ standard; add CAD and manufacturing assets
    Restructure the repo per the open-source SOP skeleton and rename the
    project to MakerChip+ (display name; repo slug unchanged):
    - Slim the README into a front-door page; move the full standard into
    spec/ (overview, magnetic, tiers, interface, docks, roadmap)
    - Apply house style (no em-dashes; Yes/No compatibility matrix)
    - Move concept image to docs/assets/; rename emakerchip-kicad -> hardware/pcb-v3
    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
    [adapter-plate.step, chip.step, dock.step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]
2026-06-17 Replace README video embed with a looping assembly GIF
    GitHub's Camo image proxy caps rendered images at ~5MB and the <video>
    tag with a raw URL does not produce a player for committed files, so
    swap both README embeds (root + manufacturing) to an animated GIF that
    loops natively and renders reliably.
    - 800px / 10fps, grain-denoised and gifsicle-optimized to 3.1MB
    - Keep the full-quality mp4 in the renders folder as the source
    - Mark *.gif binary in .gitattributes
2026-06-17 Use uploaded video asset for the looping README hero
    Swap the GIF embed for a <video autoplay loop muted playsinline> tag
    pointing at the GitHub user-attachments asset URL (full 1040x688/24fps,
    loops natively). Keep the GIF in renders/ as a portable fallback that
    also renders outside GitHub.
2026-06-17 Add design sources (Protoboard, tscircuit, 3MF prints, art); push Protoboard as the 3.x starting point
    - docs/protoboard/: add importable maker-chip-pcb-v4.protoboard + V1-V3
    JSON history; rewrite README to advertise the board (datasheets, live
    BOM, system diagram, DRC) and point at the current live board
    - README quickstart + docs table: emphasize the Protoboard project as
    the recommended 3.x starting point; update the live board link
    - hardware/makerchip-2.0/: add print-ready 3MF (chip, clear, hat-clip dock)
    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
    [chip-clear.3mf, chip.3mf, hat-clip-dock.3mf]
